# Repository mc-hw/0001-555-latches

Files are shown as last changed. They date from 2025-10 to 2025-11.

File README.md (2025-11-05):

# 555-based latches (0001)

## Description

The circuit contains of three latches: astable, monostable and bistable. Each of them is built around a separate 555
integrated circuit with configurable parameters.

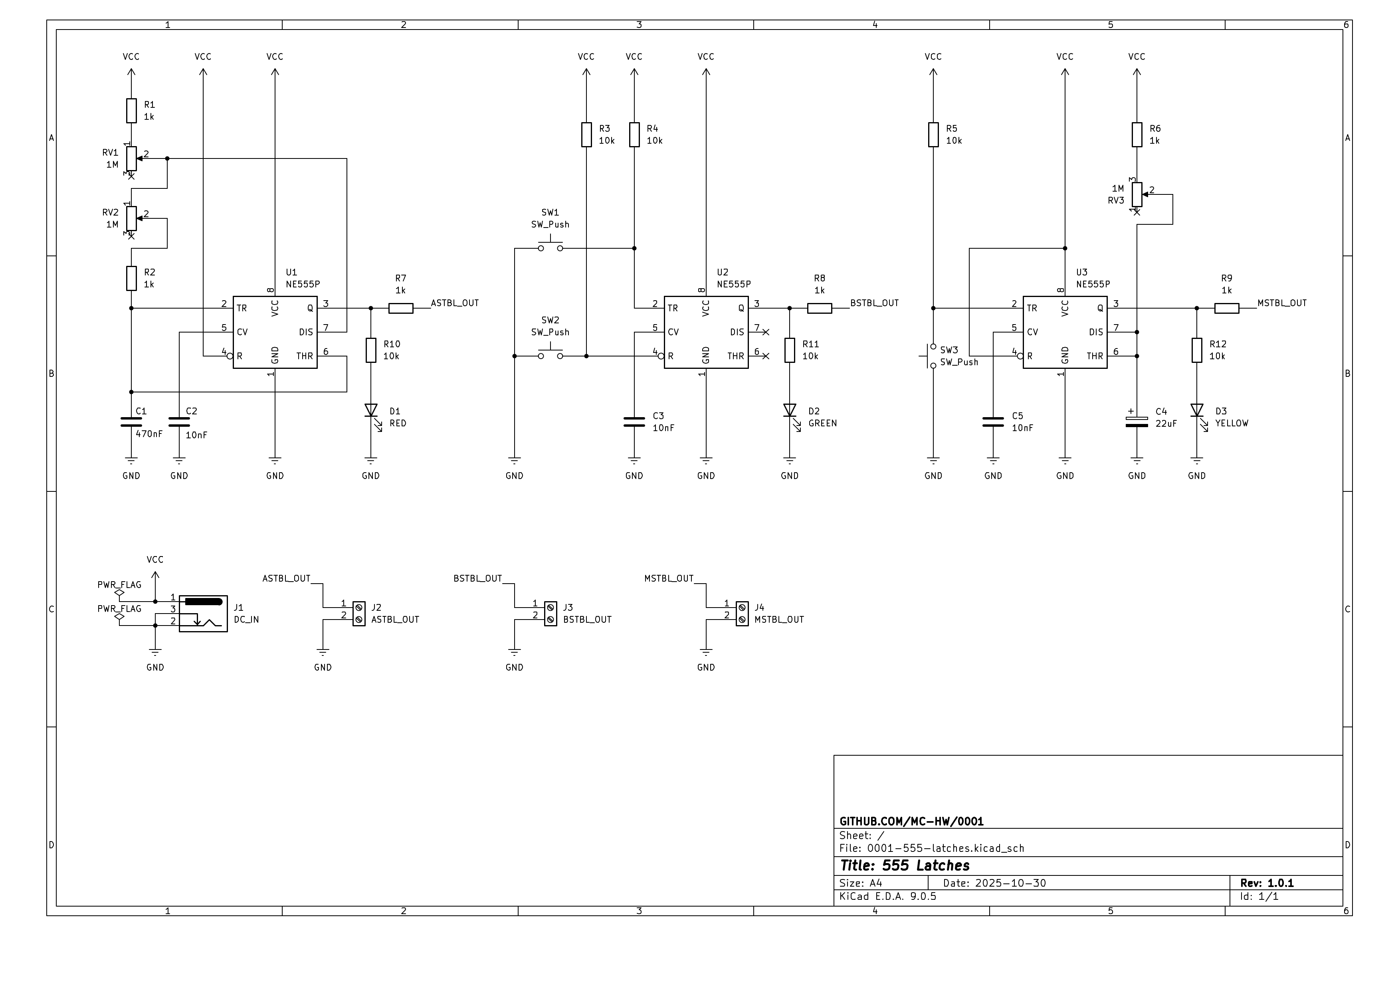
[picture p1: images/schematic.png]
Schematics


The astable latch is built around integrated circuit U1. Potentiometers RV1 and RV2, together with resistors R1, R2
and capacitor C1 regulate the frequency and duty cycle of the `ASTBL_OUT` output signal according to
[555 Timer Calculator](https://www.build-electronic-circuits.com/circuit-calculator-conversion/555-timer-calculator/).
The frequency range is 1Hz-1kHz. The `ASTBL_OUT` signal is provided to screw connector J2. The state of `ASTBL_OUT`
signal is visualised with D1 LED.

The bistable latch is build around integrated circuit U2. Pushing SW1 button triggers high output state of `BSTBL_OUT`
signal. Pushing SW2 button triggers low output state of `BSTBL_OUT` signal. The `BSTBL_OUT` signal is provided to screw
connector J3. The state of `BSTBL_OUT` signal is visualised with D2 LED.

The monostable latch is build around integrated circuit U3. Potentiometer RV3, together with resistor R6 and capacitor
C4 regulate the pulse duration of the `MSTBL_OUT` output signal according to
[555 Timer Calculator](https://www.build-electronic-circuits.com/circuit-calculator-conversion/555-timer-calculator/).
The pulse is triggered by pushing SW3 button. The pulse duration range is 25ms-25s. The `MSTBL_OUT` signal is provided
to screw connector J4. The state of `MSTBL_OUT` signal is visualised with D3 LED.

The maximal output current of each output signal is ~15mA (input voltage/1000).

## Assembly

The circuit should be assembled on a single-sided, THT printed circuit board.

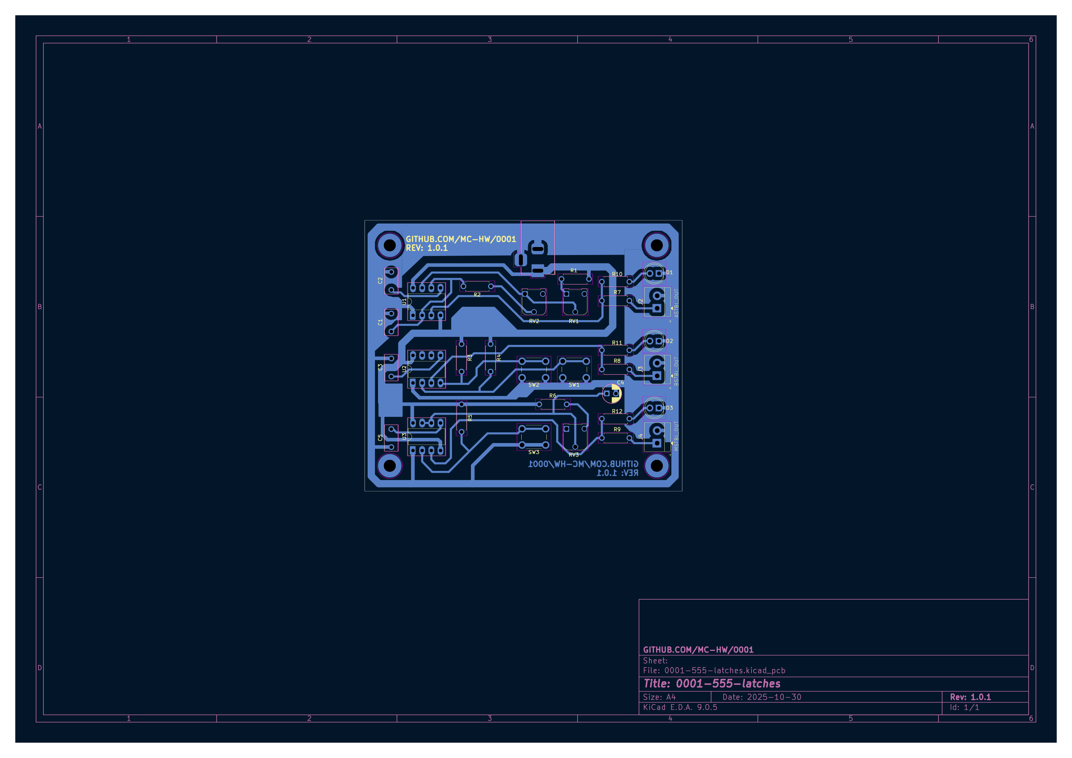
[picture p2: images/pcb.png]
PCB layout


## Running

The device should be powered with 5-15VDC provided to J1 `DC_IN` (center-positive DC jack 2.1/5.5).

After providing the voltage all output signals should be available (observe LED visualisations).

## Bill of Materials

| Reference | Qty | Value |
|---|-----|---|
| C1 | 1 | 470nF |
| C2,C3,C5 | 3 | 10nF |
| C4 | 1 | 22uF |
| D1 | 1 | RED |
| D2 | 1 | GREEN |
| D3 | 1 | YELLOW |
| J1 | 1 | DC_IN |
| J2 | 1 | ASTBL_OUT |
| J3 | 1 | BSTBL_OUT |
| J4 | 1 | MSTBL_OUT |
| R1,R2,R6,R7,R8,R9 | 6 | 1k |
| R3,R4,R5,R10,R11,R12 | 6 | 10k |
| RV1,RV2,RV3 | 3 | 1M |
| SW1,SW2,SW3 | 3 | SW_Push |
| U1,U2,U3 | 3 | NE555P |

## References

- [555 Timer Tutorial](https://www.build-electronic-circuits.com/555-timer/)
- [555 Timer Calculator](https://www.build-electronic-circuits.com/circuit-calculator-conversion/555-timer-calculator/)
- [KiCad Schematic Editor documentation](https://docs.kicad.org/9.0/en/eeschema/eeschema.html)
- [KiCad YouTube tutorial 1](https://youtube.com/playlist?list=PL3bNyZYHcRSUhUXUt51W6nKvxx2ORvUQB&si=8JaQM5K1sOJ2W4WG)
- [KiCad YouTube tutorial 2](https://youtube.com/playlist?list=PLEBQazB0HUyQ5YJSdCBb79orXaR3Uk5vm&si=labIkKh_z3xuK7w0)
- [KiCad YouTube tutorial 3](https://www.youtube.com/playlist?list=PLUOaI24LpvQPls1Ru_qECJrENwzD7XImd)
- Preparing PCBs using thermotransfer (Youtube [PL]):
    - [1](https://www.youtube.com/watch?v=IV76AiosMgo)
    - [2](https://www.youtube.com/watch?v=NjvKmZZtHUM)
    - [3](https://www.youtube.com/watch?v=1L4GrPDR9TE) - great effect
    - [4](https://www.youtube.com/watch?v=EEXGR3g5FFA) - interesting way of positioning chalk paper
    - [5](https://www.youtube.com/watch?v=SyNOZ-EPTKQ) - interesting drill technique
    - [6](https://www.youtube.com/watch?v=qdos-b2LzrI)
- Preparing PCBs using chemotransfer (Youtube):
    - [1](https://www.youtube.com/watch?v=XGvP0mEEXu8) - Interesting method with acetone/alcohol transfer
    - [2](https://www.youtube.com/watch?v=cVhSCEPINpM&t=17s) - Interesting method with polish remover transfer
    - [3](https://www.youtube.com/watch?v=wvU2yyfH-XE) - Applying solder mask
    - [4](https://www.youtube.com/watch?v=IfhOYhjXLDg) - Applying solder mask

## Implementation

### Breadboard testing

Circuits were tested using breadboard before assembly. Each latch was tested separately.

Testing site:

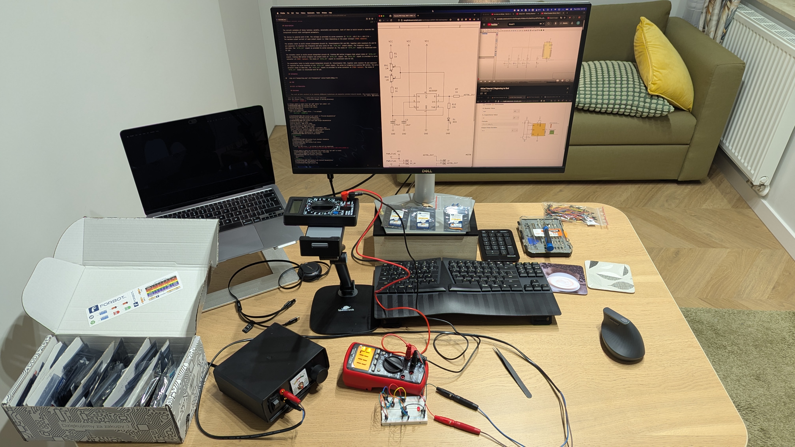
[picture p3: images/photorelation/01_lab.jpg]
Testing lab


555 integrated circuit in the bread board:

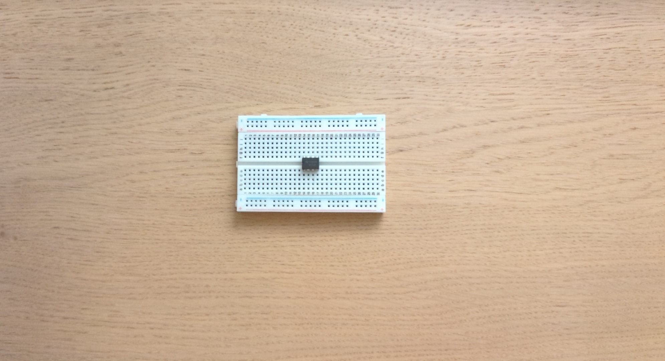
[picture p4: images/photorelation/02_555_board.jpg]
555 in bread board


Minimal astable latch configuration resistance measurement:

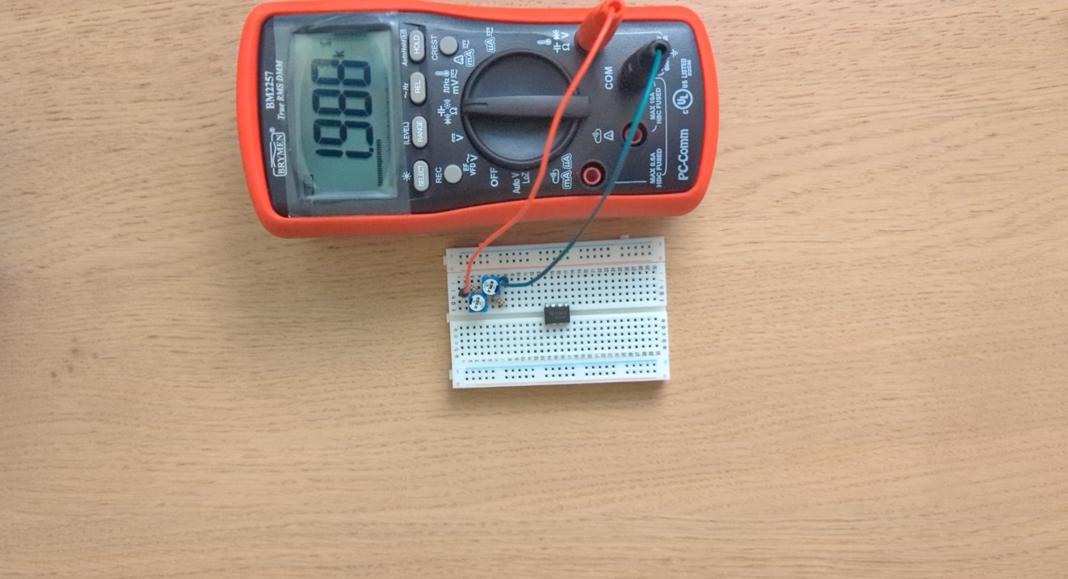
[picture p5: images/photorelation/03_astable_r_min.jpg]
Min astable resistance


Maximal astable latch configuration resistance measurement:

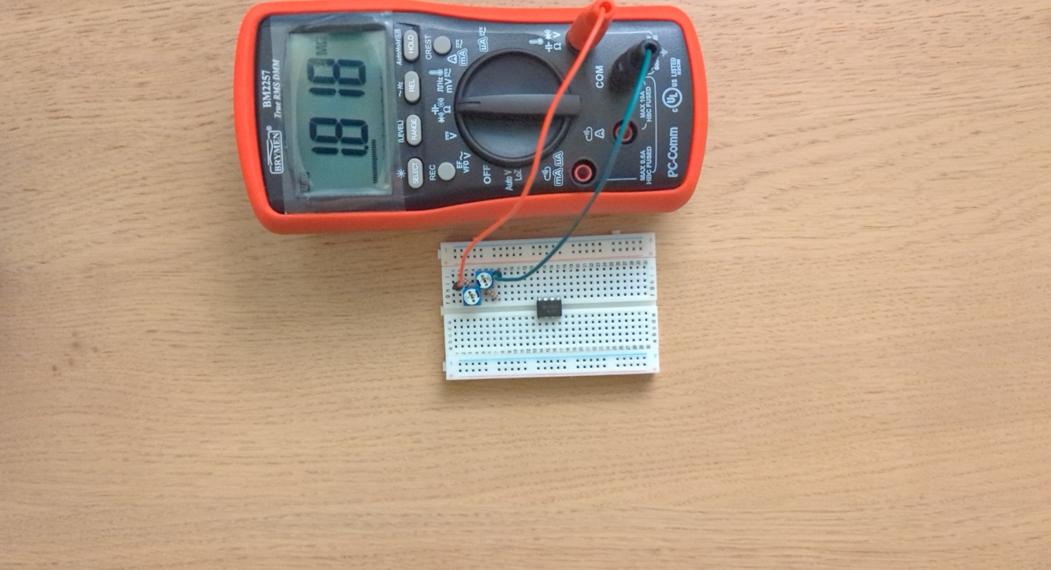
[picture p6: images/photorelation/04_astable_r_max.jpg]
Max astable resistance


Astable latch testing circuit ready:

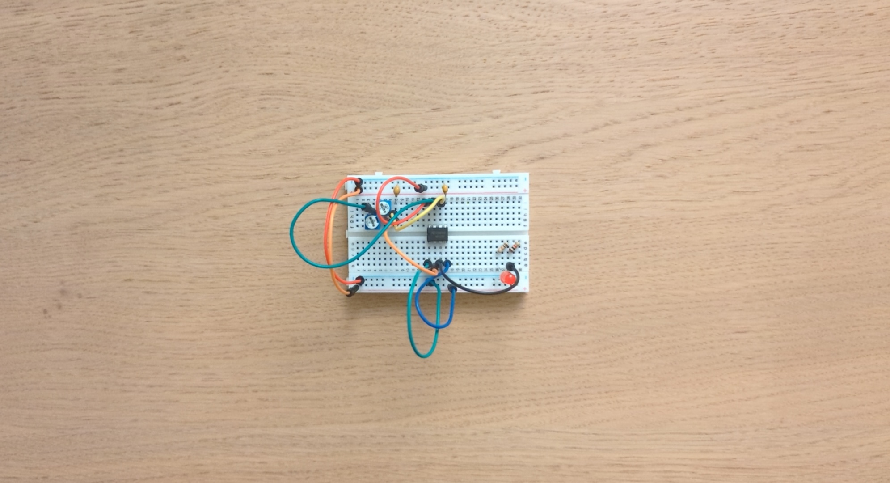
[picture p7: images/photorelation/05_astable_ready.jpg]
Astable testing circuit ready


Last astable latch continuity testing before providing power:

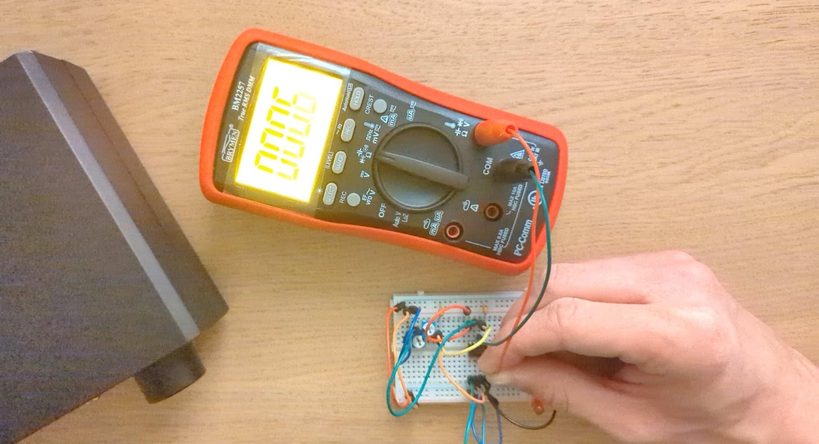
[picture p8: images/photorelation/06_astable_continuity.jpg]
Continuity test


Astable latch maximal frequency measurement:

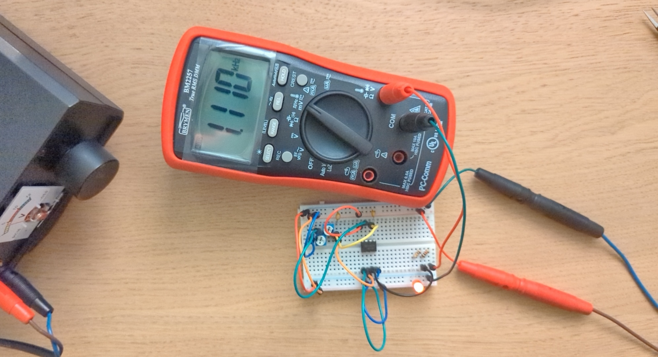
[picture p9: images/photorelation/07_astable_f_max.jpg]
Max astable frequency


Astable latch minimal frequency measurement:

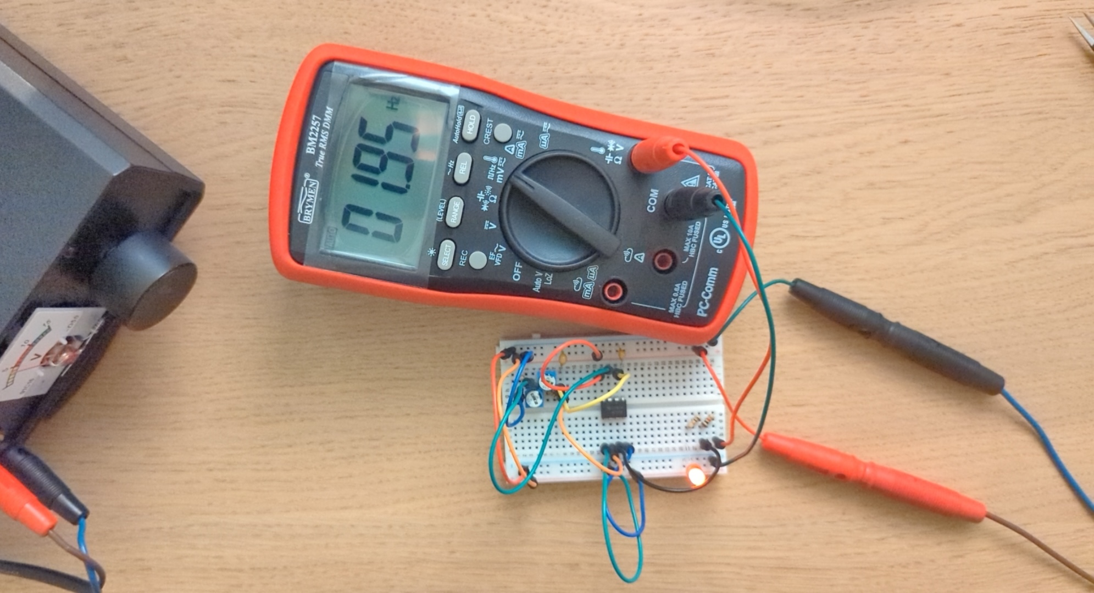
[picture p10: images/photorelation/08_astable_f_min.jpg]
Min astable frequency


Astable latch maximal current measurement:

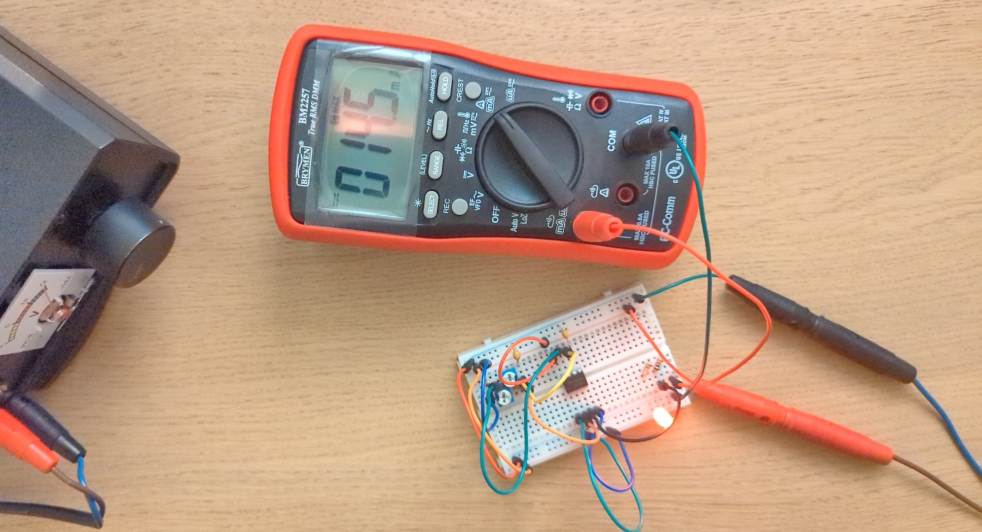
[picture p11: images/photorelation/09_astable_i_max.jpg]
Max astable current


Bistable latch testing:

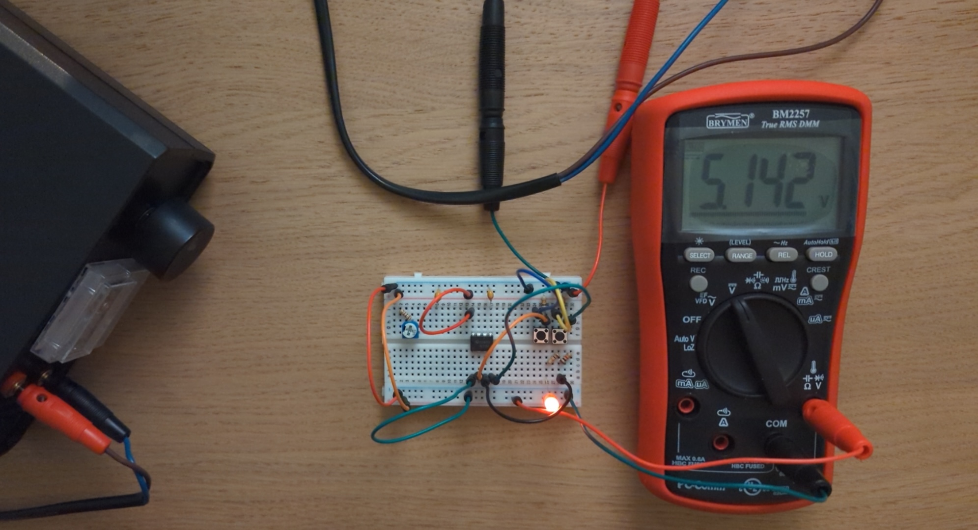
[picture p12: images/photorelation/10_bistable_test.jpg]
Testing bistable latch


Monostable latch testing:

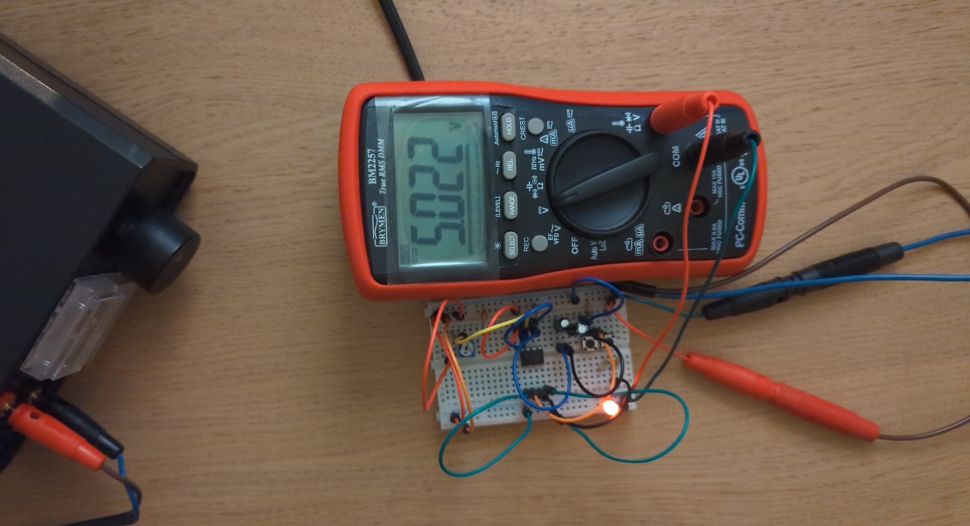
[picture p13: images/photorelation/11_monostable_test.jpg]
Testing monostable latch


### PCB preparation

#### Mark 1

The printout for the first instance of PCB was printed on the page from magazine.

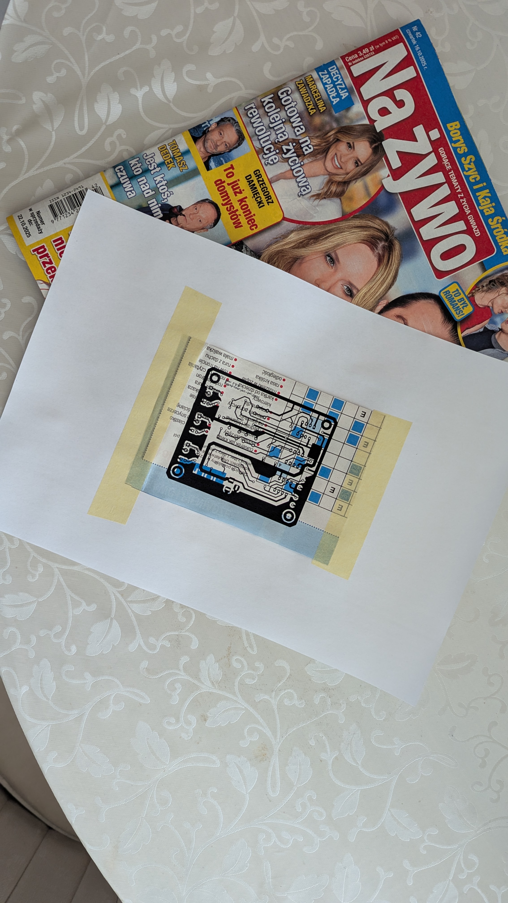
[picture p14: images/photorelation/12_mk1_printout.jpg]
Mark 1 printout


The surface was prepared for transfer using cleaning milk, sand paper (1000, wet) and isopropanol.

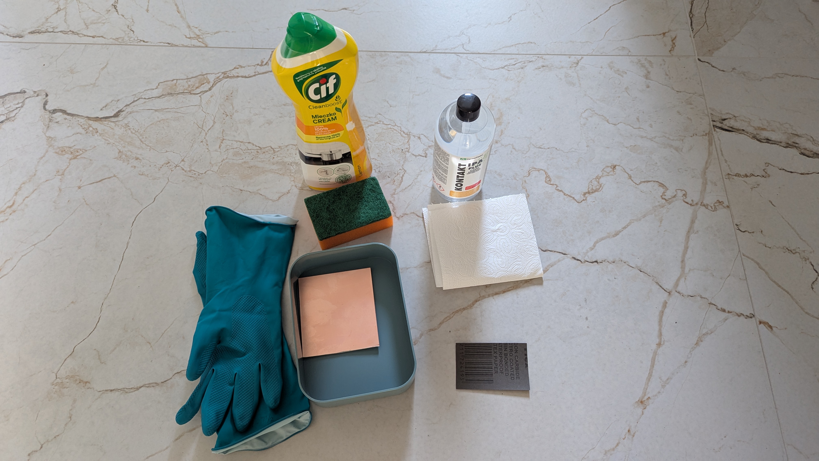
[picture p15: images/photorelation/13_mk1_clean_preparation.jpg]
Mark 1 cleaning


Next the printout was stuck to the copper using paper tape and doused with Moisturising polish remover.

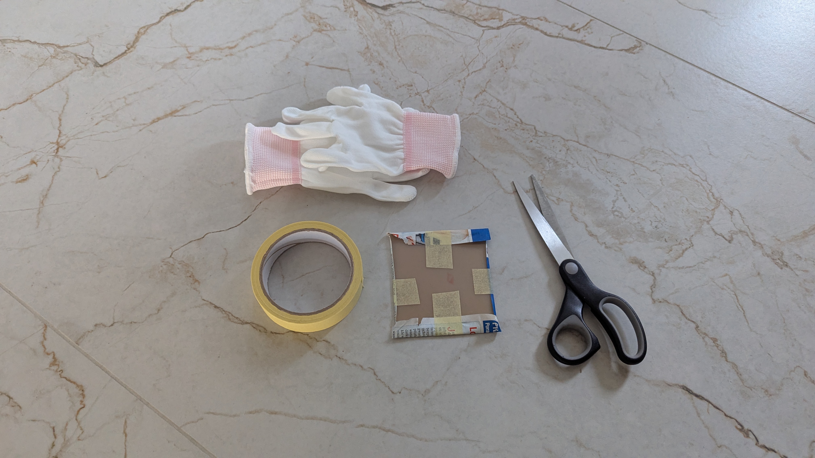
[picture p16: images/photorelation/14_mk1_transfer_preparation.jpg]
Mark 1 transfer preparation

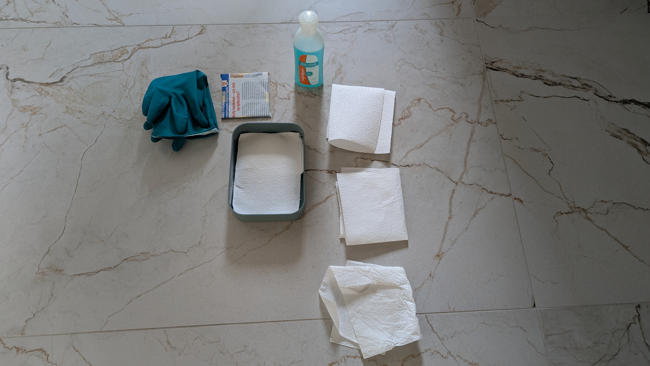
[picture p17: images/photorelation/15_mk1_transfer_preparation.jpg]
Mark 1 transfer preparation

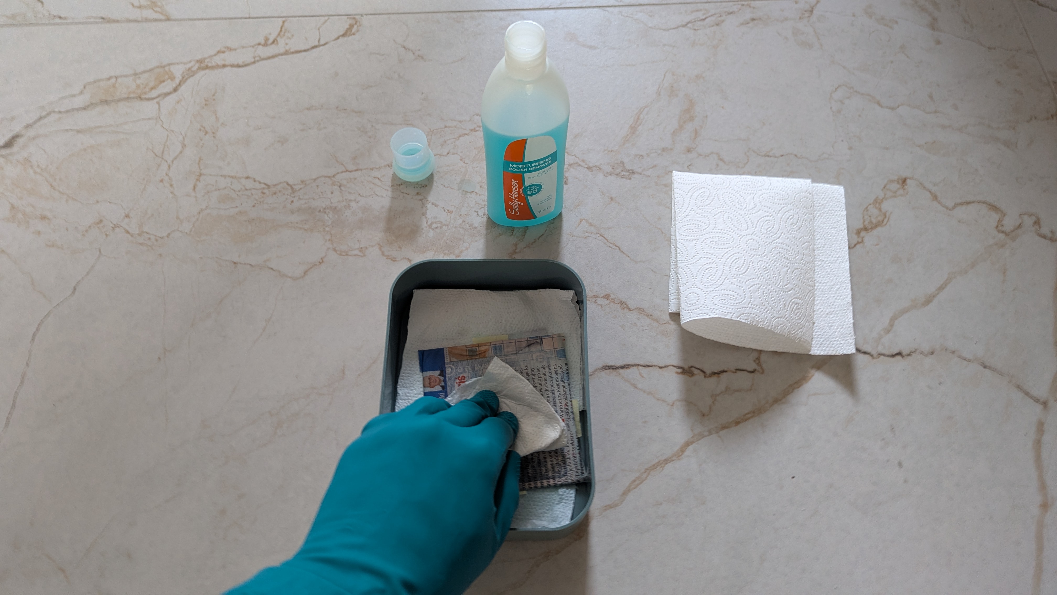
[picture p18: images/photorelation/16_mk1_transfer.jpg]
Mark 1 transfer


The remaining of paper was removed in warm water with dish soup

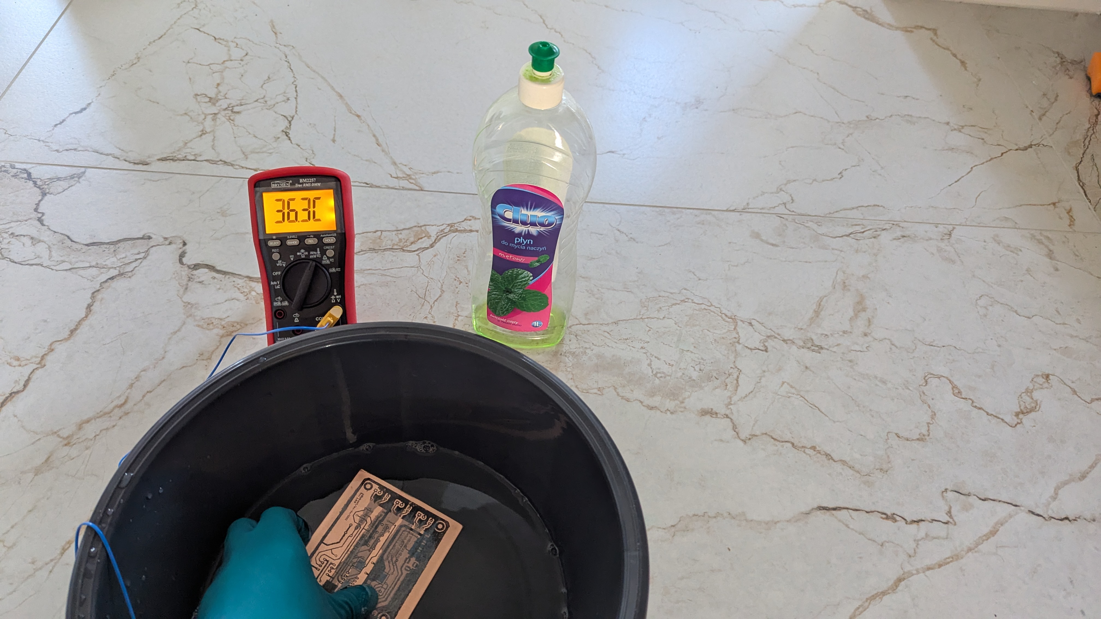
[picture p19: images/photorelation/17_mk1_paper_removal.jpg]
Mark 1 paper removal

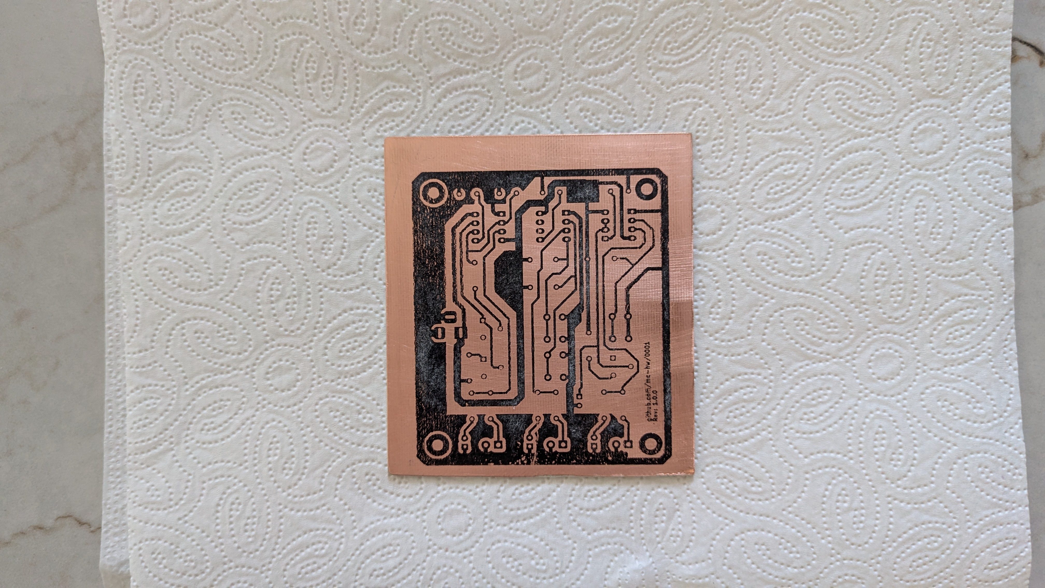
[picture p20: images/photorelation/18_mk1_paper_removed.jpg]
Mark 1 paper removed


The result was far from perfect, so the decision was to start again.
The traces were removed using nitro:

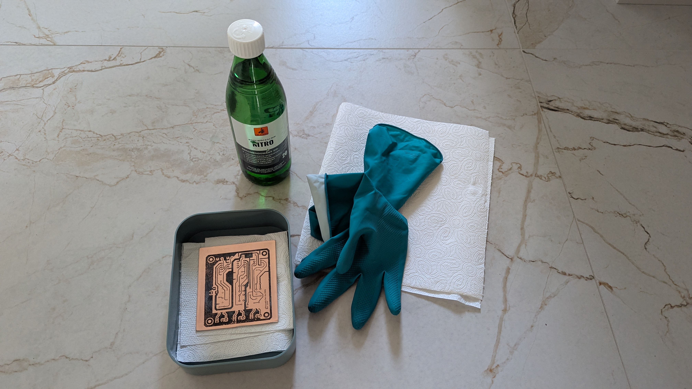
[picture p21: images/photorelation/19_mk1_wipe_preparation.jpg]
Mark 1 wipe preparation

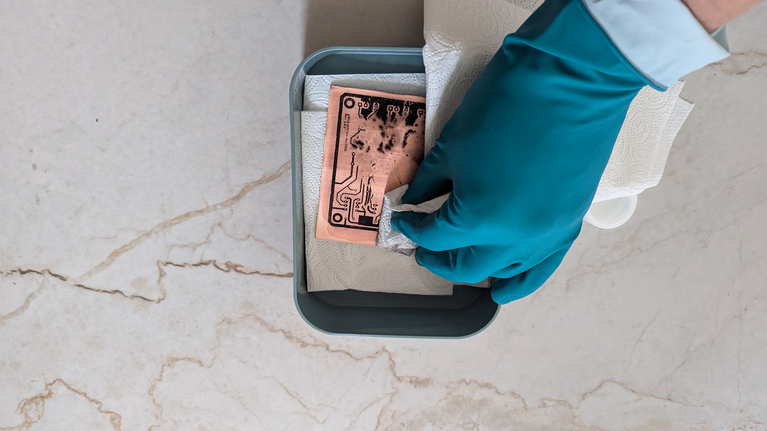
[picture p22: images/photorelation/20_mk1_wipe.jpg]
Mark 1 wipe

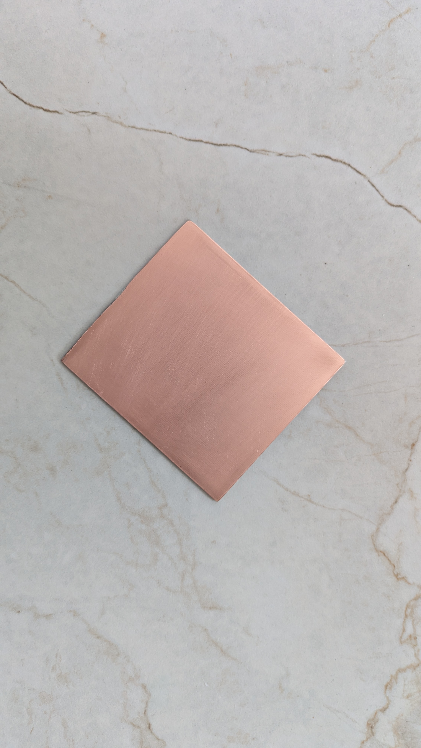
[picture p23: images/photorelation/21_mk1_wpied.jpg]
Mark 1 wiped


#### Mark 2

The traces were printed on the glossy side of thermotransfer paper. Unfortunately, the result was bad. Another try was
printing on the magazine page, this time more glossy.
**For the future, in KiCad print dialog, try 'Drill Marks: Small mark'.**

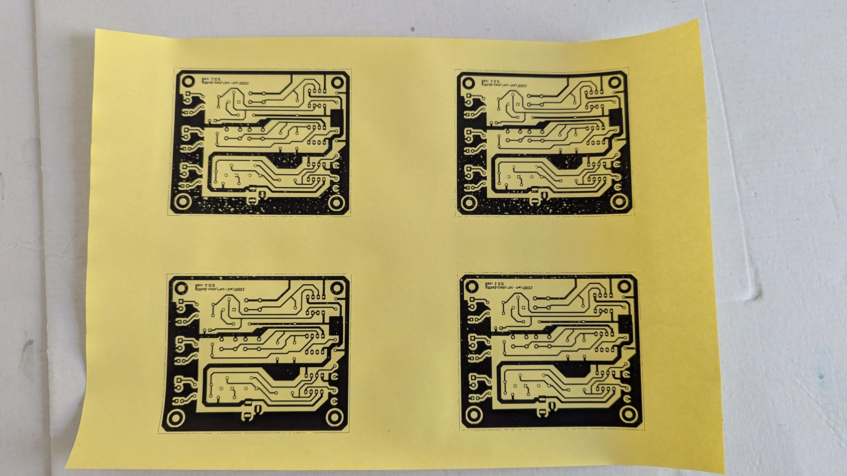
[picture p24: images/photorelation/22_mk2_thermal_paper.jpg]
Mark 2 thermal paper


The surface was again cleaned with Acetone.

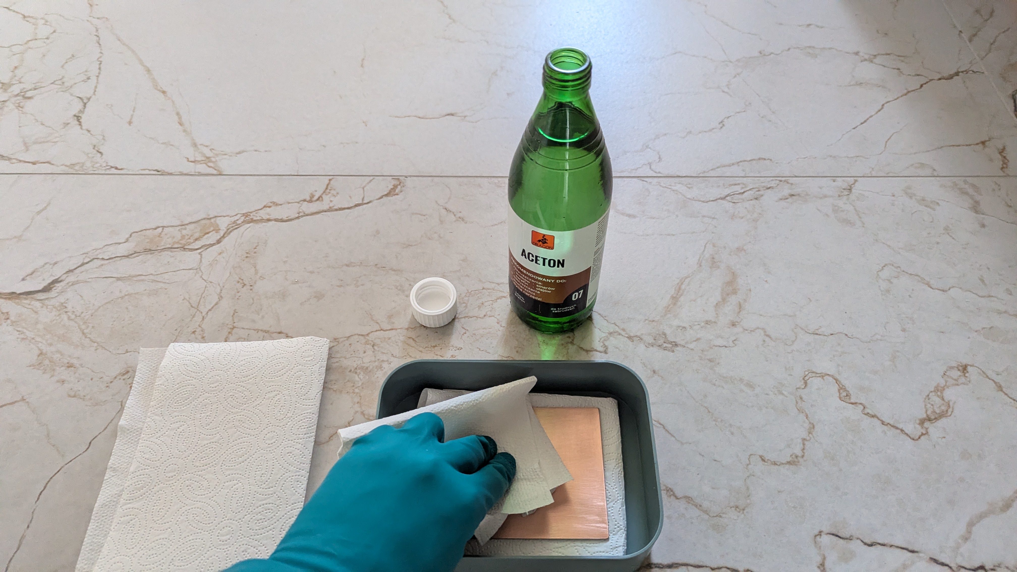
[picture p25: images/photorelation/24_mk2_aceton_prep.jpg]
Mark 2 Acetone preparation


The printout was fine cut this time and stuck to the surface.

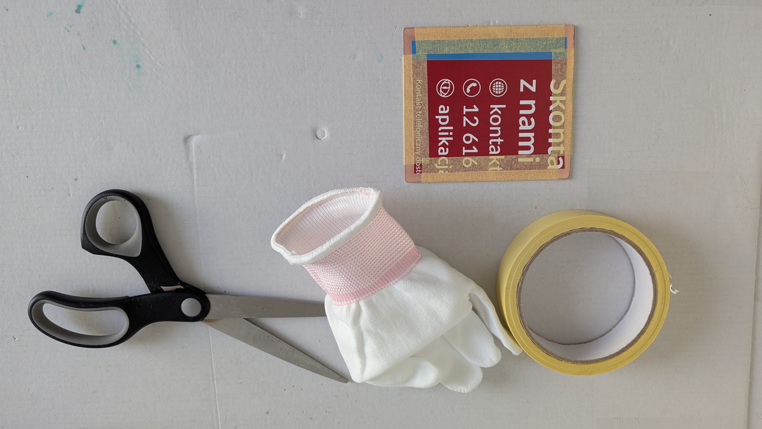
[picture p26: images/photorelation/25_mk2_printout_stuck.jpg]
Mark 2 printout stuck


The paths were transferred using Moisturising polish remover again.

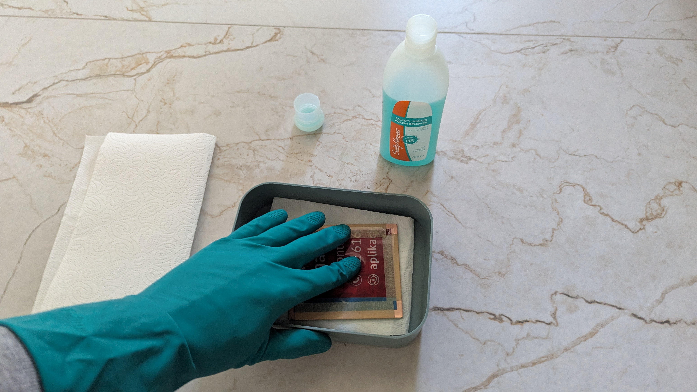
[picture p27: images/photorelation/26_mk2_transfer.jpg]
Mark 2 transfer


The paper did not come out easily, so it was put into warm water with dish soap.

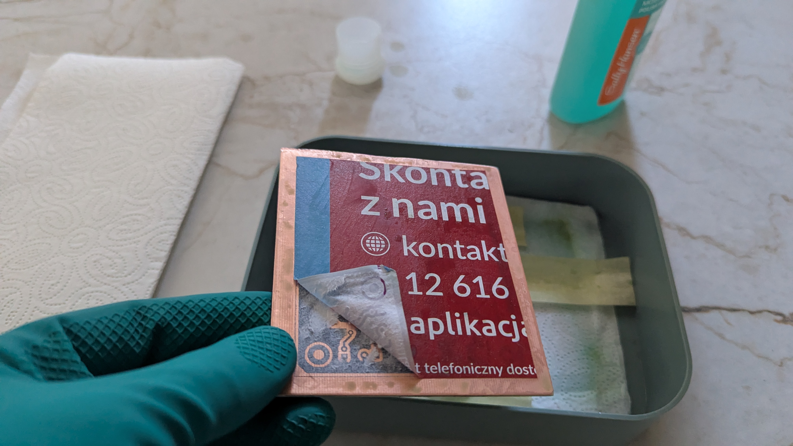
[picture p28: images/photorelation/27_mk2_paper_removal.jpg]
Mark 2 paper removal

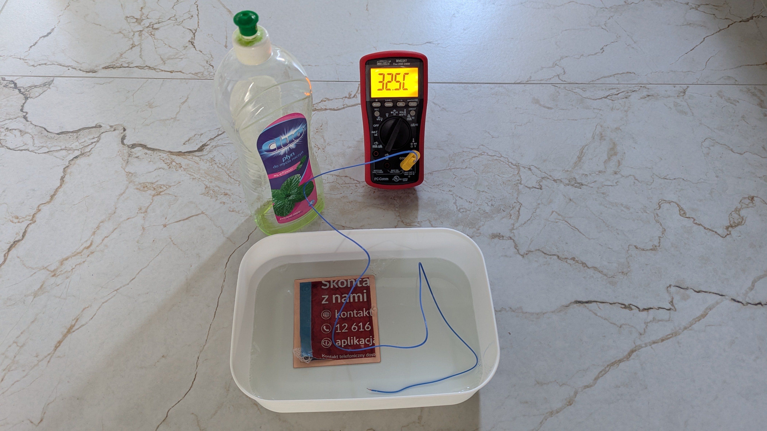
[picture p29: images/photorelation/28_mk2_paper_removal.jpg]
Mark 2 paper removal


The traces required corrections, which were done using corrector and permanent marker.

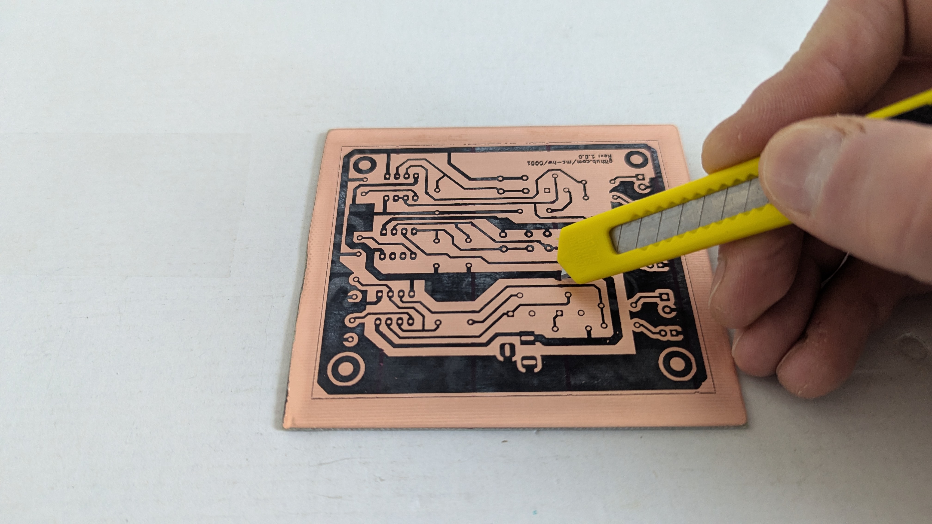
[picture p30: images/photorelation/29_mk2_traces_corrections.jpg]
Mark 2 traces corrections

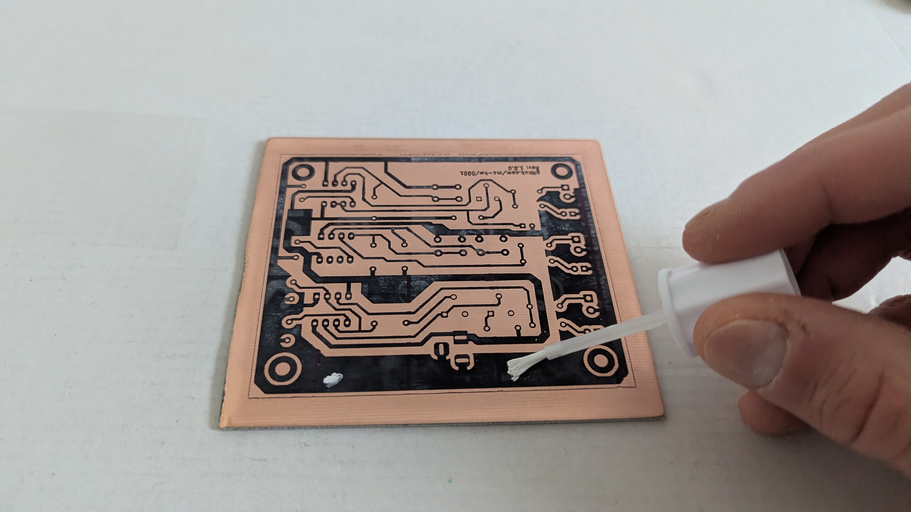
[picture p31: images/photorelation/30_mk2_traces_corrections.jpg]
Mark 2 traces corrections

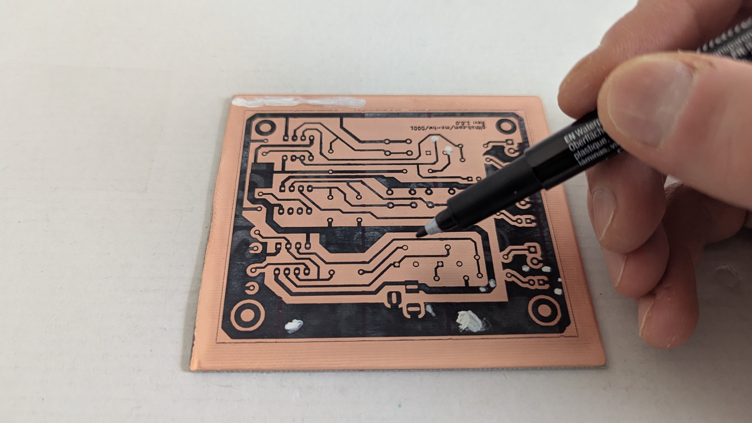
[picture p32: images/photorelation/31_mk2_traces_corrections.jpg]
Mark 2 traces corrections

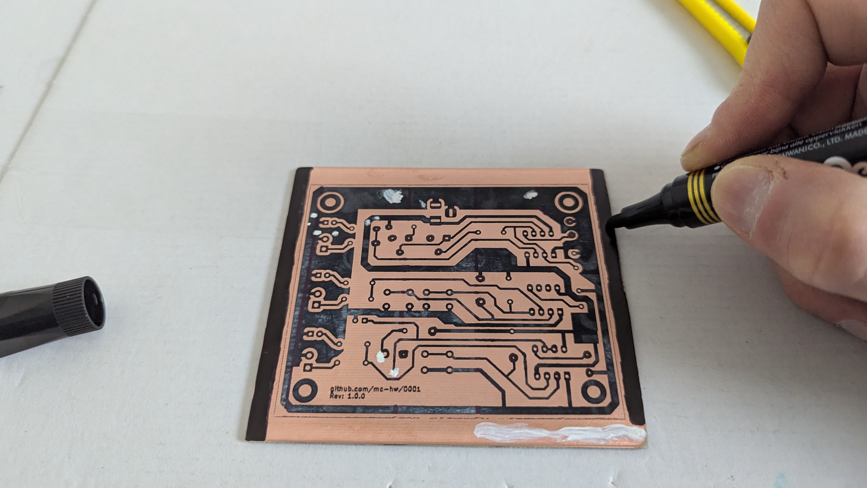
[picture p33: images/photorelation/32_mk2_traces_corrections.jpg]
Mark 2 traces corrections

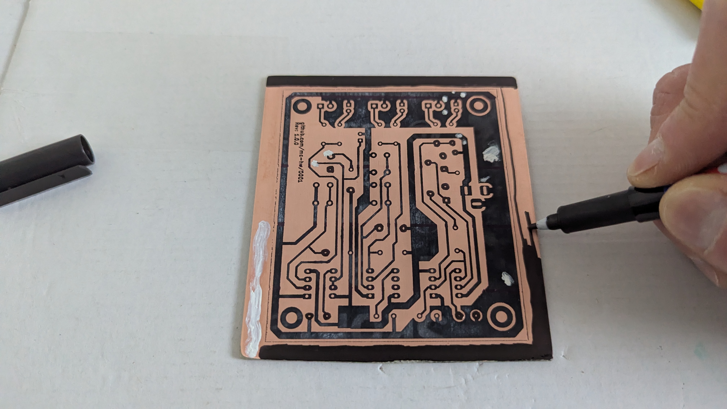
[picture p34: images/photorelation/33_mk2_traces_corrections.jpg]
Mark 2 traces corrections

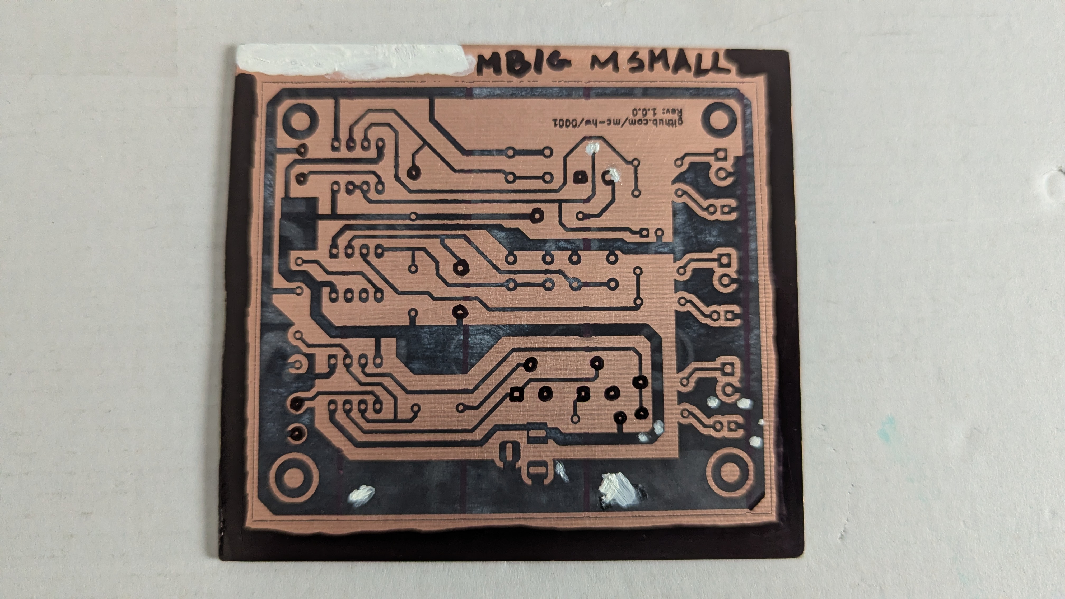
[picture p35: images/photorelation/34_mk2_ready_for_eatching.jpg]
Mark 2 ready for etching


The etcher was prepared according to instructions.

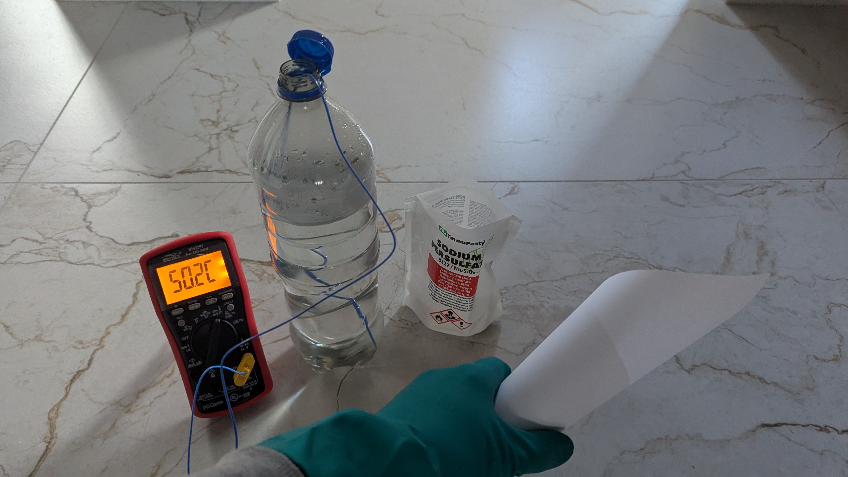
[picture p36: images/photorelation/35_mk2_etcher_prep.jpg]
Mark 2 etcher preparation


PCB was etched in 50 degrees Celsius.

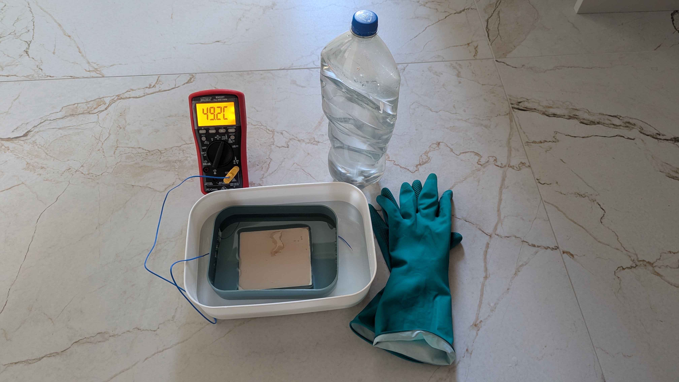
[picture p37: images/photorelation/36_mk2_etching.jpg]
Mark 2 etching


Toner was removed with Nitro. (**For the future: Use capital letters on custom text. Apply text also in the mask
layer**).

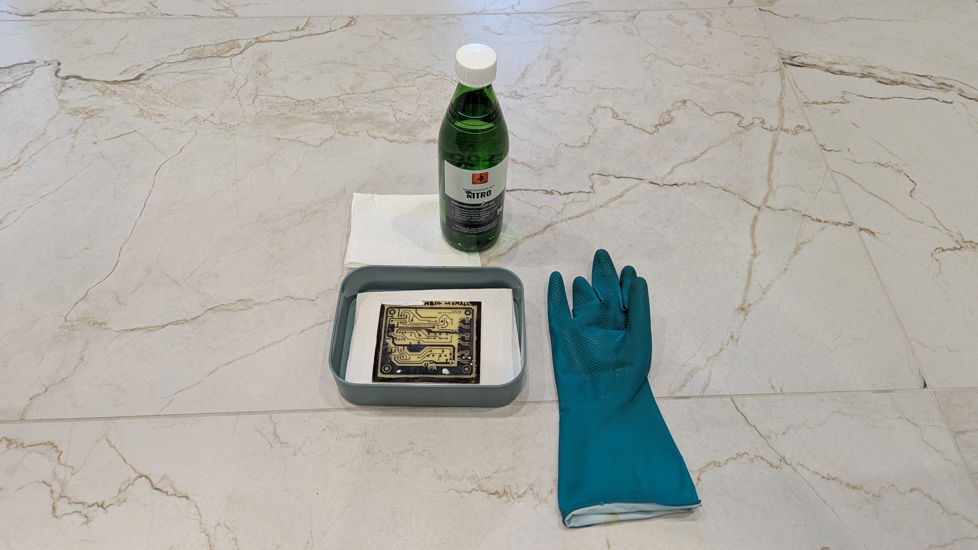
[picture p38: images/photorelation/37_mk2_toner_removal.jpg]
Mark 2 toner removal

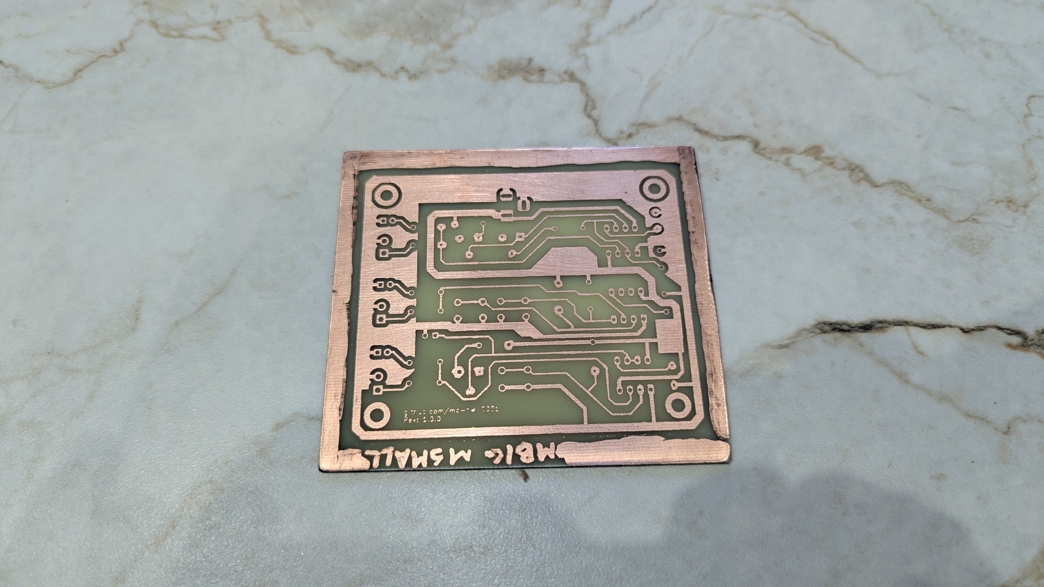
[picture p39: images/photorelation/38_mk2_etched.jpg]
Mark 2 etched


The drilling of mounting points was performed using hand drill. **For the future: table drill is a must.**

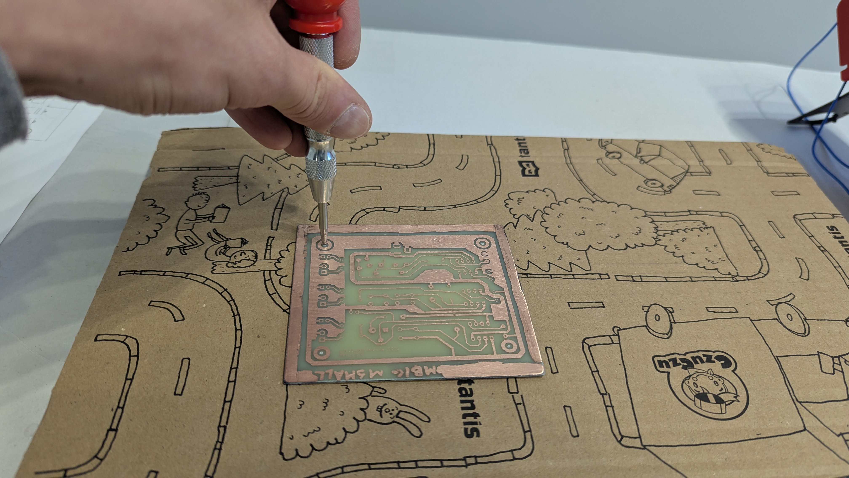
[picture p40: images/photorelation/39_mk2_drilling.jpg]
Mark 2 drilling

Mark 2 drilling

The front side of PCB was skimmed with Isopropanol.

Mark 2 front preparation

The silk screen was printed on the glossy leaflet and aligned to the mounting point holes.

Mark 2 leaflet printout
Mark 2 leaflet alignment

The silk screen was transferred using Acetone/Isopropanol solution (50/50).

Mark 2 leaflet transfer

The result was miserable, so the layer was removed with Acetone.

Mark 2 leaflet removal

Another try was printing on the magazine page (the same as for back side, Mk2). The following layers were printed:
F.Silkscreen, User.Comments (for mounting points visibility), Edge.Cuts, F.Courtyard.

Mark 2 magazine printout

The silkscreen was transferred using Moisturising polish remover. The result was OK, but not perfect.
**For the future: Use capital letters for custom text**.

Mark 2 magazine transfer
Mark 2 magazine removal

The paper was removed with vinegar/water solution (30/70).

Mark 2 magazine remobal
Mark 2 front ready

The PCB was skimmed using Isopropanol and dried with hot air before solder mask application.

Mark 2 degreasing
Mark 2 drying

The blue _Relief_ solder mask was applied using plastic card.

Mark 2 solder mask application
Mark 2 solder mask application
Mark 2 solder mask application

The F.Mask layer with 'No drill mark' option was used as a stencil. **For the future: Place printed side of the stencil
up, multiple layers. 2 hours could be too long (mask was hard even under the stencil). Use matt film.**

Mark 2 solder mask application

The solder mask was hardened using UV diode light (~2h), pressed with a glass dish, but the effect was far from
expected, the dish is not perfectly flat (**For the future: try pressing with glass**).

Mark 2 solder mask hardening

The solder mask was removed from fields using Acetone (best so far, Isopropanol also is promising). However, mask didn't
get of fields where it was thickest. Fields were also covered with toner (**For the future: Place printed side of the
stencil up.**) and was only partially removed. It was unfortunately not equally thick (**For the future: try pressing
with glass**).

Mark 2 solder mask from fields removal

On the front side solder mask was applied using brush. The effect was much better than using plastic card.
Although, the layer was too thick. It was also not equally thick.

Mark 2 front solder mask application
Mark 2 front solder mask application

The remaining, not hardened solder mask was removed using Acetone. Silkscreen was surprisingly well visible.

Mark 2 solder mask cleanup

Sandpaper (1000) was used to remove covered fields. Unfortunately, it also removed large part of solder mask itself.

Mark 2 solder mask sandpaper
Mark 2 solder mask sandpaper
Mark 2 solder mask sandpaper result

The front side was covered with solder mask again. This time with brush but the bubbles were removed through the film
using plastic card.

Mark 2 solder mask bubbles removal

Solder mask was hardened for ~1 hour.

Mark 2 solder mask hardening

After first hardening solder mask was cleaned up and left for hardening again.

Mark 2 solder mask cleanup
Mark 2 solder mask hardening
Mark 2 solder mask front

Another solder mask application was done after pressing double stencil printed up with acryl plexi. The surface was
cleaned up first with Isopropanol.

Mark 2 cleaning
Mark 2 back UV

The mask was cleaned up with Acetone. **For the future: try shorter hardening. The mask was hard to remove.**

Mark 2 solder mask cleanup

After removing the mask, the surface was hardened again.

Mark 2 solder mask hardening

The front side was de-glossed using sandpaper (grade 3000). The effect was OK, but using mat film is better.

Mark 2 degloss

The silkscreen was transferred using chalk paper and iron.

Mark 2 cleaning
Mark 2 silkscreen transfer
Mark 2 silkscreen transfer

The effect exceeded expectations.

Mark 2 back effect
Mark 2 front effect

Half of fields were tinned before drilling. Seems like a good idea to tin first.

Mark 2 tinning


Half of fields were punched before drilling. **For the future: avoid punching, try only on biggest fields.**

Mark 2 punching

Drilling was performed using table drill.

Mark 2 drill
Mark 2 drill

After cutting edges, the final effect was as below. **For the future: try cutting on the initial phase of PCB
production.**

Mark 2 cutting
Mark 2 final back
Mark 2 final front

#### Mark 3

- For Mark 3 a copper piece (~120 x ~100 mm) was cut. The edges were smoothed with file.
- The surface (both sides) were cleaned with cleaning milk, sand paper (1000), Acetone and Isopropanol.
- The copper layer was printed on a big piece of glossy page from magazine, 'Small drill mark' option selected.
- The paths were transferred using Moisturising polish remover with paper wrapped around copper as envelope (seems worse
  than fine-cut piece).
- The paths were corrected with marker, corrector and scalpel.
- The holes for mounting points were drilled after etching, before toner removal.
- After etching toner was removed using Acetone.
- The PCB was cleaned with Isopropanol and dried with hot air (270 degrees Celsius).
- The front side of PCB was covered with tape before solder mask application.
- _Mechanic_ solder mask was applied using a plastic card through a stencil printed down on mat film. On top of it
  another stencil, printed down on glossy film was placed. It was pressed between two acryl panes and left for 10
  minutes to spread evenly.
- The first UV hardening took 30 minutes, half by half, from 10cm.
- The fields were removed with Isopropanol. Unfortunately, the result was poor. Longer hardening needed? Also the layer
  was too thick.

Mark 3 final front
Mark 3 final back

#### Mark 4

- For Mark 4 a copper piece (~120 x ~100 mm) was cut. The edges were smoothed with a file.
- The surface (both sides) were cleaned with cleaning milk, sand paper (1000), Acetone and Isopropanol.
- The copper layer was printed on a big piece of glossy page from magazine, 'Small drill mark' option selected.
- The paths were transferred using Moisturising polish remover with paper fine cut and stuck to copper using paper tape.
- The PCB was fine-cut, the edges were smoothed with a file and sandpaper (grade 150). The file was a bad idea.
- The paths were corrected with marker and scalpel.
- The holes for mounting points were drilled after etching.
- After etching toner was removed using Acetone.
- The entire PCB (both sides, edges) was smoothed with sandpaper (grade 1000) and cleaned with Nitro (outperforms even
  Acetone).
- _Mechanic_ solder mask was applied using a plastic card through a stencil printed down on mat film. On top of it
  another stencil, printed down on glossy film was placed. It was pressed between two acryl panes.
- The first UV hardening took 45 minutes, equally covered by light, from 20cm.
- The fields were removed with Isopropanol. They were also corrected by Acetone, but it seems to be too aggressive.
  Unfortunately, the result was poor. Also, the layer was too thick.
- The missing parts of back side solder mask was covered with brush and toothpick.
- Fields were tinned before drilling.

Mark 4 final front
Mark 4 final back

#### Mark 5

- For Mark 5 a copper piece (~120 x ~100 mm) was cut. The edges were smoothed with a file. Seems to be a bad idea,
  solder mask is fragile and breaks, it's better to fine-cut before etching.
- The surface (both sides) were cleaned with cleaning milk, sand paper (1000), Acetone and Isopropanol.
- The copper layer was printed on a big piece of glossy page from magazine, 'No drill mark' option selected.
- The paths were transferred using Moisturising polish remover with paper fine cut and stuck to copper using paper tape.
- The PCB was fine-cut, the edges were smoothed with a file and sandpaper (grade 150). The file was a bad idea.
- The paths were corrected with marker and scalpel.
- The holes for mounting points were drilled before etching. Seems to be a good idea, holes were smoother after etching.
- After etching toner was removed using Acetone.
- The entire PCB (both sides, edges) was smoothed with sandpaper (grade 1000) and cleaned with Acetone.
- Both sides were painted with a colophony dissolved in Nitro (seems like a bad idea, stencil got stuck).
- _Mechanic_ solder mask was applied using a plastic card through a stencil printed down on mat film (printed twice). On
  top of it another stencil, printed down on glossy film was placed. It was pressed between two acryl panes.
- The first UV hardening took 90 minutes (each corner first, 15 minutes, central later, 30 minutes).
- The fields were removed with Isopropanol.
- The front side was cleaned with Isopropanol before solder mask application. The back side was covered with tape.
- _Mechanic_ solder mask was applied to the front side using a plastic card through a matt film. It was pressed between
  two acryl panes, but the top glass was removed before hardening.
- The UV hardening took 1 hour (each corner first, 10 minutes, central later, 20 minutes).
- The film was removed millimeter by millimeter, starting with corners, holding with a plastic card.
- The result was OK, but it was better when the hardening time was longer.
- Both sides were again painted with a colophony dissolved in Nitro

Mark 5 final front
Mark 5 final back

#### Mark 6

- For Mark 6 a copper piece (~120 x ~100 mm) was cut. The edges were smoothed with a file.
- The surface (both sides) were cleaned with cleaning milk, sand paper (1000), Acetone and Isopropanol.
- The copper layer was printed on a big piece of glossy page from magazine, 'No drill mark' option selected.
- The paths were transferred using Moisturising polish remover with paper fine cut and stuck to copper using paper tape.
- The PCB was fine-cut, the edges were smoothed with a file and sandpaper (grade 150). The file was a bad idea.
- The paths were corrected with marker and scalpel.
- The holes for mounting points were drilled before etching. Seems to be a good idea, holes were smoother after etching.
- After etching toner was removed using Acetone.
- The entire PCB (both sides, edges) was smoothed with sandpaper (grade 1000) and cleaned with Nitro (outperforms even
  Acetone).
- The front side of PCB was covered with tape before solder mask application.
- _Mechanic_ solder mask was applied using a plastic card through a stencil printed down on mat film (printed twice). It
  was pressed between two acryl panes, but the top glass was removed before hardening.
- The UV hardening took 1 hour 15 minutes (each corner first, 15 minutes, central later, 15 minutes).
- The stencil was removed millimeter by millimeter, starting with corners, holding with a plastic card. The fields were
  removed with Isopropanol. The result was pretty OK. The fields were smaller than expected, try shortening the
  hardening time.
- The front side was cleaned with Isopropanol before solder mask application. The back side was covered with tape.
- _Mechanic_ solder mask was applied to the front side using a plastic card through a matt film. It was pressed between
  two acryl panes, but the top glass was removed before hardening.
- The UV hardening took 1.5 hour (each corner first, 20 minutes, central later, 30 minutes).
- The stencil was removed millimeter by millimeter, starting with corners, holding with a plastic card. The fields were
  removed with Isopropanol. The result was pretty good. Could consider shorter hardening.
- The silkscreen was printed (twice) on chalk paper and transferred with iron.
- Corners were again covered with solder mask, where it was missing. The result was OK, but try another layer of solder
  mask.
- Fields were tinned before drilling.

Mark 6 final front
Mark 6 final back

## PCB ordering

Gerber files should be generated for each PCB manufacturer individually, every manufacturer have a different
requirements for Gerber files. There is no general solution which could be generated upfront for each manufacturer.

Only manufacturers, who allow initiating orders using Gerber/KiCAD files were selected.

Considered manufacturers:

- [Satland Prototype (pl)](https://www.prototypy.com/sites_pcbplugins/pcborder/58)
- [Laskar (pl)](https://laskar.com.pl/): Minimal order - 20 dm2, PLN 365 net for single-sided board.
- [Margol (pl)](https://www.fabrykapcb.pl/index.html)
- [EMS Electronix (pl)](https://www.ems-elektronix.com/zapytania-ofertowe/#formularz-ofertowy)
- [ts (pl)](https://tspcb.pl/zamow-wycen/)
- [PCB Way (ch)](https://www.pcbway.com/)
- [multi-cb (de)](https://portal.multi-circuit-boards.eu/)

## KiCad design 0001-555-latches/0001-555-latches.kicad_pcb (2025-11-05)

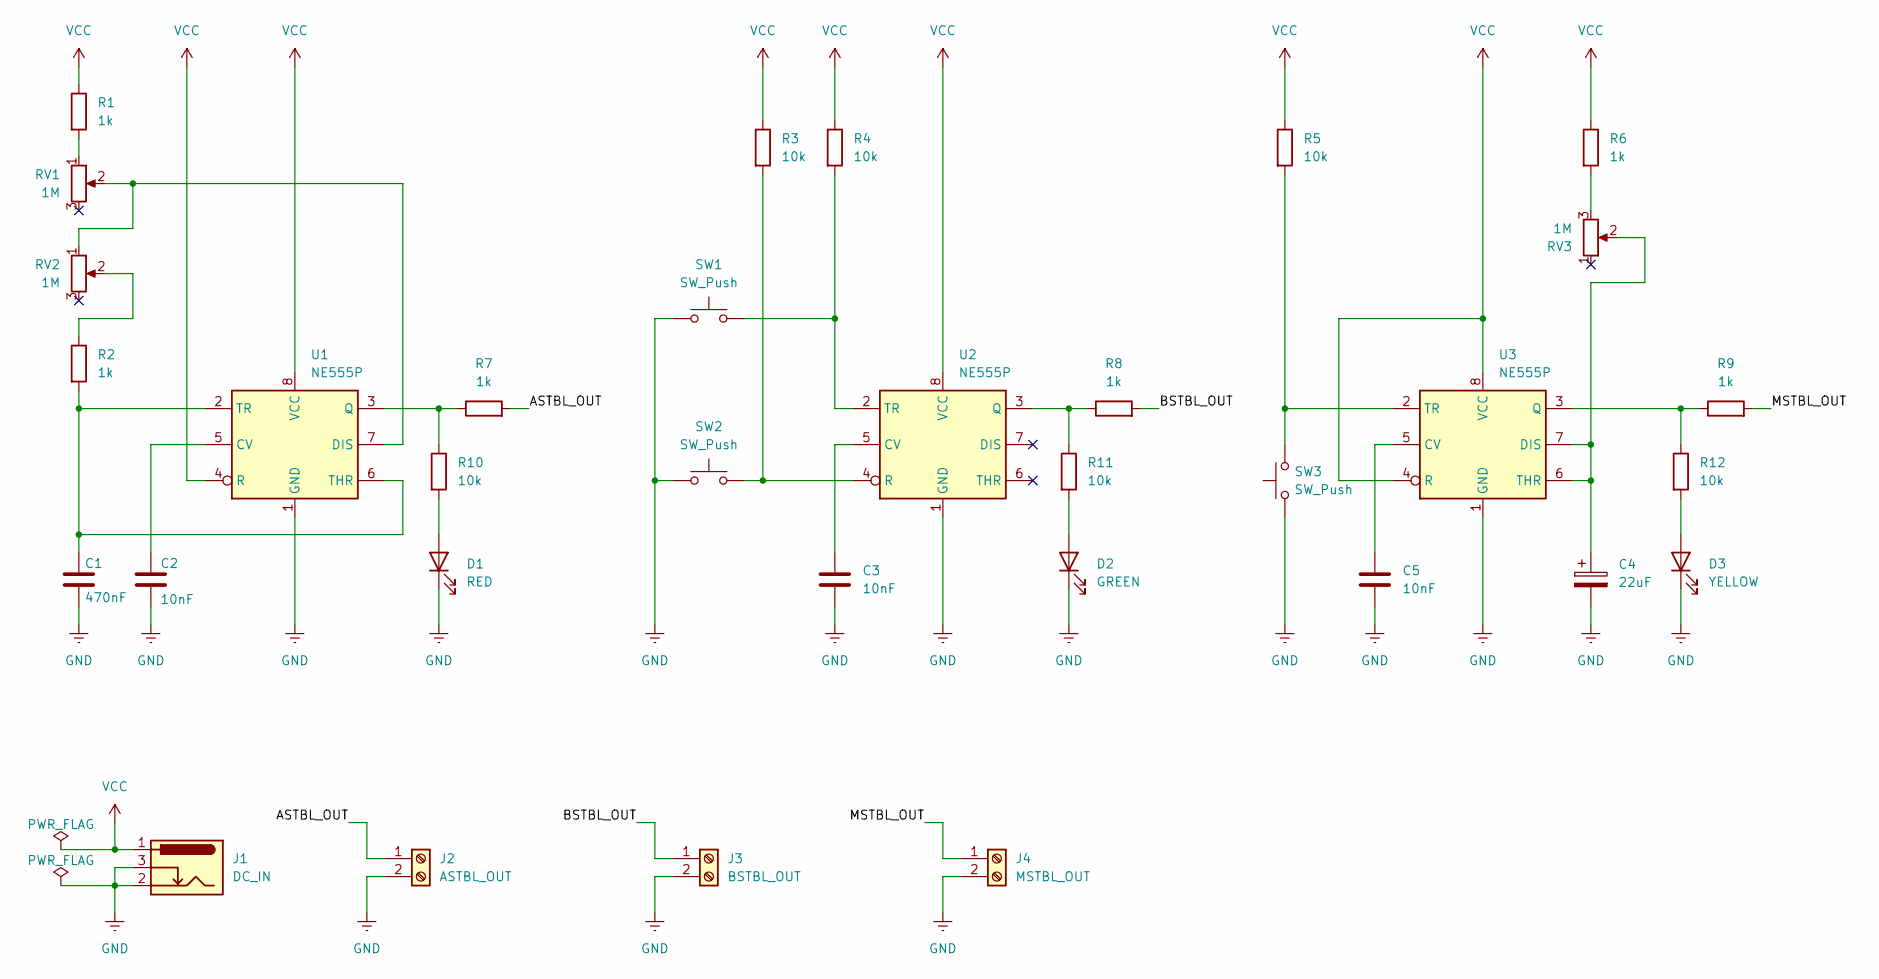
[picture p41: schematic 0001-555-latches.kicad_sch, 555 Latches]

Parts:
C1: 470nF; C_Rect_L7.0mm_W3.5mm_P5.00mm
C2, C3, C5: 10nF; C_Rect_L7.0mm_W3.5mm_P5.00mm
C4: 22uF; CP_Radial_D5.0mm_P2.00mm
D1: RED; LED_D5.0mm
D2: GREEN; LED_D5.0mm
D3: YELLOW; LED_D5.0mm
J1: DC_IN; BarrelJack_Horizontal
J2: ASTBL_OUT; TerminalBlock_4Ucon_1x02_P3.50mm_Horizontal
J3: BSTBL_OUT; TerminalBlock_4Ucon_1x02_P3.50mm_Horizontal
J4: MSTBL_OUT; TerminalBlock_4Ucon_1x02_P3.50mm_Horizontal
R1, R2, R6, R7, R8, R9: 1k; R_Axial_DIN0207_L6.3mm_D2.5mm_P7.62mm_Horizontal
R3, R4, R5, R10, R11, R12: 10k; R_Axial_DIN0207_L6.3mm_D2.5mm_P7.62mm_Horizontal
RV1, RV2, RV3: 1M; Potentiometer_Runtron_RM-065_Vertical
SW1, SW2, SW3: SW_Push; SW_PUSH_6mm_H4.3mm
U1, U2, U3: NE555P; DIP-8_W7.62mm_Socket_LongPads

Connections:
/ASTBL_OUT: J2.1, R7.2
/BSTBL_OUT: J3.1, R8.2
/MSTBL_OUT: J4.1, R9.2
GND: C1.2, C2.2, C3.2, C4.2, C5.2, D1.1 (K), D2.1 (K), D3.1 (K), J1.2, J1.3, J2.2, J3.2, J4.2, SW1.1, SW2.1, SW3.1, U1.1 (GND), U2.1 (GND), U3.1 (GND)
unnamed: D1.2 (A), R10.2
unnamed: D2.2 (A), R11.2
unnamed: D3.2 (A), R12.2
unnamed: R1.2, RV1.1
unnamed: R2.1, RV2.2
unnamed: R6.2, RV3.3
unnamed: C2.1, U1.5 (CV)
unnamed: RV1.2, RV2.1, U1.7 (DIS)
unnamed: R7.1, R10.1, U1.3 (Q)
unnamed: C1.1, R2.2, U1.2 (TR), U1.6 (THR)
unnamed: C3.1, U2.5 (CV)
unnamed: R8.1, R11.1, U2.3 (Q)
unnamed: R3.2, SW2.2, U2.4 (R)
unnamed: R4.2, SW1.2, U2.2 (TR)
unnamed: C5.1, U3.5 (CV)
unnamed: C4.1, RV3.2, U3.6 (THR), U3.7 (DIS)
unnamed: R9.1, R12.1, U3.3 (Q)
unnamed: R5.2, SW3.2, U3.2 (TR)
VCC: J1.1, R1.1, R3.1, R4.1, R5.1, R6.1, U1.4 (R), U1.8 (VCC), U2.8 (VCC), U3.4 (R), U3.8 (VCC)

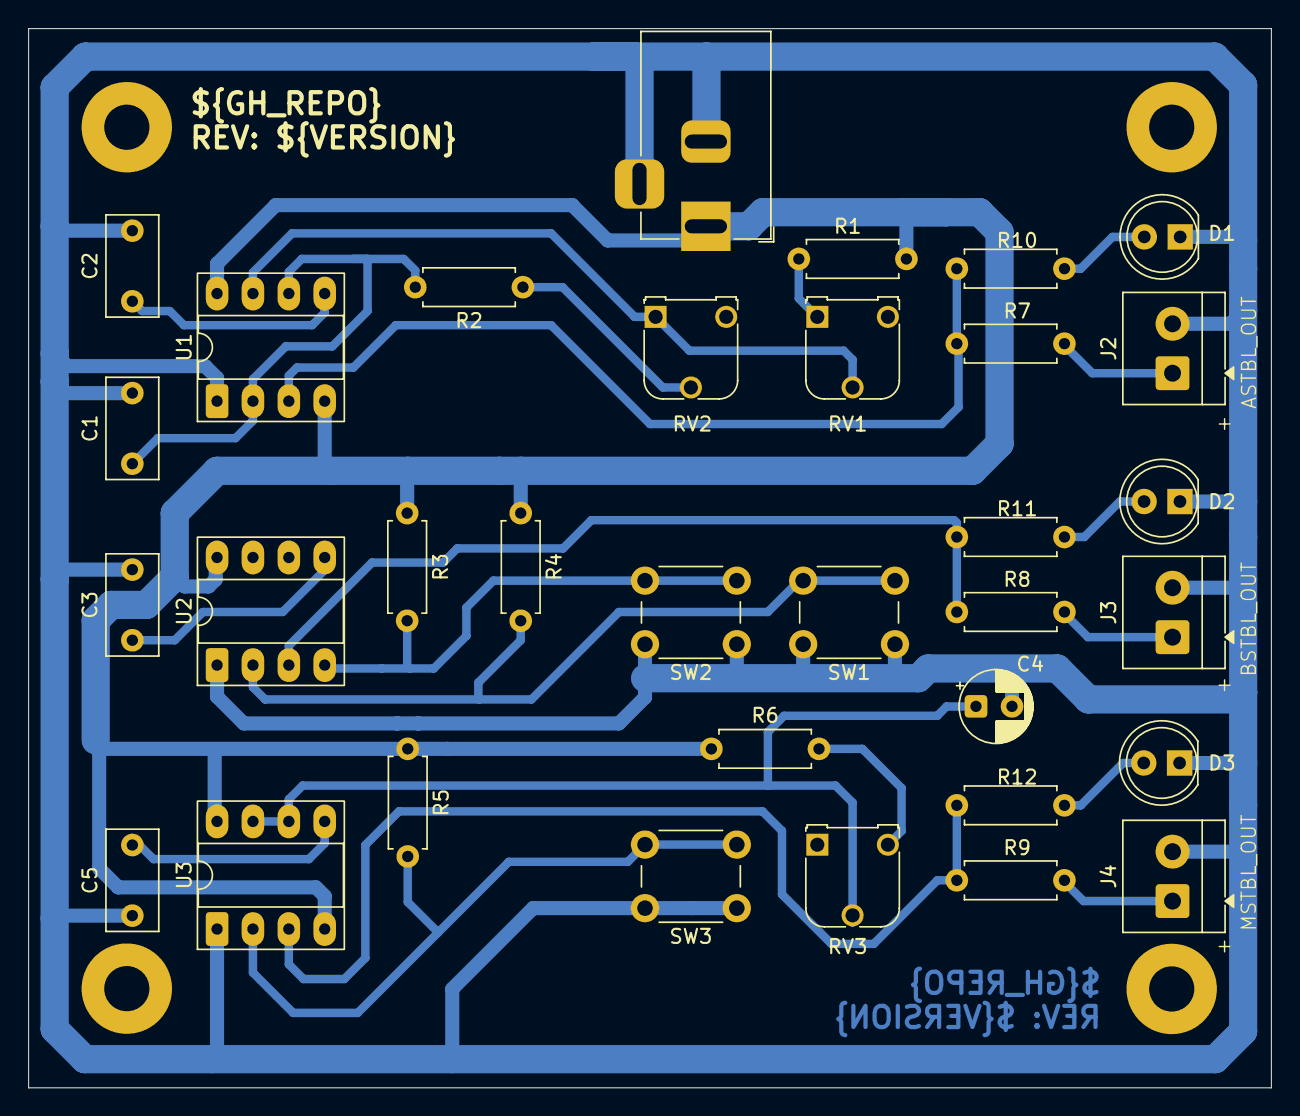
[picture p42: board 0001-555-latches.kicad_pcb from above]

Board: 2 copper layers, 88.0 x 75.0 mm, 37 parts (0 on the bottom side), 23 nets.

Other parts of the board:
MNT1, MNT2, MNT3, MNT4: MountingHole_3.2mm_M3_Pad

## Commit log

2025-10-11 Initial schematics, astable, bistable
    [0001-555-latches.kicad_pcb, 0001-555-latches.kicad_sch]
2025-10-11 Monostable latch schematics
    [0001-555-latches.kicad_sch]
2025-10-11 Schematics validation
    [0001-555-latches.kicad_sch]
2025-10-11 Elements values
    [0001-555-latches.kicad_sch]
2025-10-11 Update values and symbols of monostable capacitor
    [0001-555-latches.kicad_sch]
2025-10-11 Improve schematics layout
    [0001-555-latches.kicad_sch]
2025-10-11 Update version
    [0001-555-latches.kicad_sch]
2025-10-11 Fixes after tutorials
    [0001-555-latches.kicad_sch]
2025-10-11 Update potentiometers leads, replace junctions
    [0001-555-latches.kicad_sch]
2025-10-12 Documentation (#2)
    * Documentation template
    * Add schematic
    * Provide documentation
    * Photorelation
    * Fix typos
    * Update document structure
    * Documentation updates
    * PCB layout and gerber placeholders
    * Update images
    * Update assembly and running sections
    ---------
2025-10-17 Pcb layout (#3)
    * footprints
    * Fix typo
    * First PCB drafts
    * All PCB connections
    * Replace DC_IN screw connector with DC jack
    * PCB compression
    * Optimizing tracks
    * PCB labels (copper/silk)
    * Closing PCB
    * Validation
    * Tracks optimisation
    * PCB layout corrections
    * Add PCB layout to documentation
    * Update tracing
    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
    [0001-555-latches.kicad_pcb, 0001-555-latches.kicad_sch]
2025-10-18 Update PCB (#4)
    * Update PCB
    * PCB ordering candidates
    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
    [0001-555-latches.kicad_pcb]
2025-10-24 Implementation (#5)
    * Update GH organisation in PCB
    * Correcting files
    * Fix formatting
    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
    [0001-555-latches.kicad_pcb]
2025-10-27 Pcb production (#6)
    * Mark 1
    * Mark2 - photorelation
    * Mark 2 - relation
    * Solder mask conclusion
    * Solder mask conclusions
    * Solder mask continuation
    * Small corrections
    * Solder mask name
    * Mark 2 solder mask
    * Change formatting
    * Change formatting
    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
2025-10-31 Pcb mk2 (#7)
    * Finishing PCB mk2
    * Correction
    * Correction
    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
2025-11-05 Pcb mk3,4,5,6 (#8)
    * Update labels on PCB
    * Mk 3, 4, 5, 6
    * Mark 3
    * Mk 4
    * Mark 6
    * Mk6 - solder mask finished
    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
    [0001-555-latches.kicad_pcb]
